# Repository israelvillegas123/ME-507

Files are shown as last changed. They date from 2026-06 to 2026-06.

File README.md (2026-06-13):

# Desk Buddy Robot

Desk Buddy is a small autonomous desk companion robot built around an STM32F411 microcontroller. The robot uses VL53L0X Time of Flight sensors to avoid falling off a desk, DC motors with encoders for movement, servo-driven llama ears for expressive behavior, and an SSD1306 OLED display for facial animations.

## Documentation

Project documentation can be found at:
(https://israelvillegas123.github.io/ME-507/index.html)

## Repository Structure

- Core/ - Application source code
- Drivers/ - STM32 HAL drivers
- USB_DEVICE/ - USB CDC implementation
- docs/ - Doxygen documentation pages
- Doxyfile - Doxygen configuration

## Authors

- Israel Villegas
- Antony Chen

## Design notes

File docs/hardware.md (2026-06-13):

# Hardware {#hardware}

## Hardware Overview

The Desk Buddy is built around an STM32F411 microcontroller and a custom PCB that connects all of the sensors, motors, and user interface components. The robot uses sensors to detect the edge of a desk, while motors and servos allow it to move and interact with the user.

---

## Main Controller

### STM32F411CEU6

The STM32F411CEU6 is the main microcontroller used in the project. It acts as the brain of the robot and is responsible for reading sensor data, controlling the motors and servos, updating the display, and making decisions about how the robot should behave.

---

## Sensors

### Time of Flight Sensors

Three VL53L0X Time of Flight distance sensors are mounted on the front of the robot. These sensors measure the distance to nearby objects and help the robot from falling off the edge. The VL53L0X sensors communicate with the STM32 microcontroller using the I2C interface and provide accurate distance measurements in a compact package.

---

## Actuators

### DC Motors with Encoders

The robot moves using two DC gear motors. Each motor includes an encoder that measures wheel rotation. The encoder feedback allows the software to monitor wheel speed and improve motor control.

### Servo Motors

Two servo motors are used to move the robot's arms. These arms are used to give the robot personality and make it feel more interactive.

---

## User Interface

### OLED Display

A SSD1306 OLED display is mounted on the front of the robot and is used to show facial expressions and animations. The display communicates with the STM32 microcontroller over an I2C interface and serves as the primary visual interface for the robot.

---

## Bill of Materials

| Component | Qty | Purpose |
| --- | ----- | --- |
| STM32F411CEU6 | 1 | Main microcontroller |
| DC Gear Motor with Encoder | 2 | Drive the robot and provide speed feedback |
| DRV8833 Motor Driver | 1 | Control the DC motors |
| Servo Motor | 2 | Move the robot arms |
| VL53L0X ToF Sensor | 3 | Distance measurement and edge detection |
| SSD1306 I2C OLED Display | 1 | Display faces and status information |
| 7.4 V LiPo Battery | 1 | Power source |

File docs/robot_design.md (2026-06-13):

# Robot Design {#robot_design}

## Overview

The Desk Buddy was designed to look like a small llama while still providing enough space for the electronics, battery, sensors, and motors.

The goal was to create a robot that feels more like a desk friend than a traditional robot. The final design has a simple design with features that give the robot personality, including movable ears and animated facial expressions displayed on an OLED screen.

---

## CAD Model

The robot was modeled in CAD before 3D printing it and checking overall dimensions.

<div align="center">
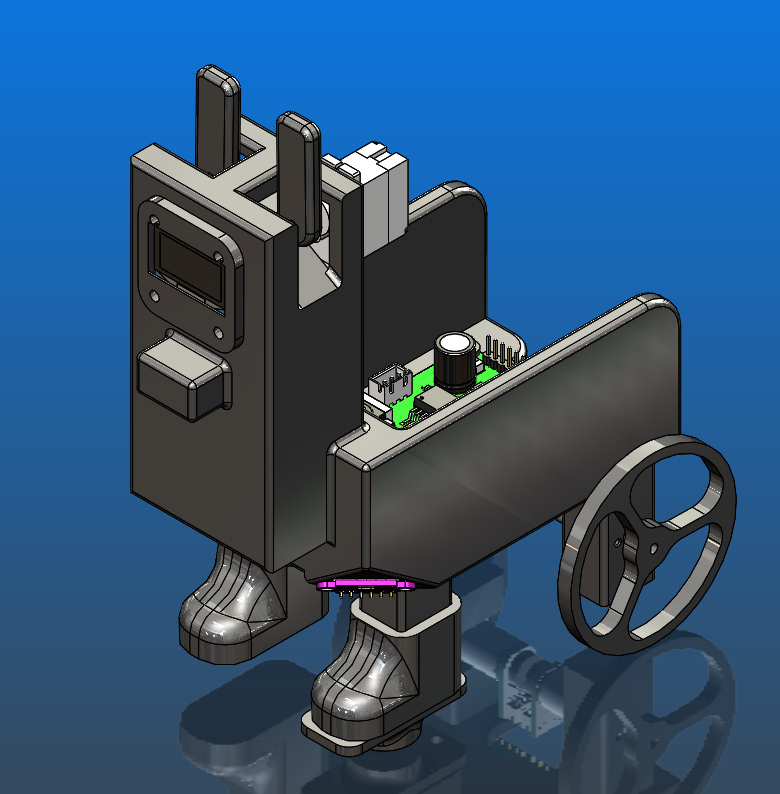
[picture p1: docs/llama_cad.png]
    
    <p><em>Figure 1: CAD model of the Desk Buddy robot.</em></p>
</div>

---

## Ear Mechanism

One of the main design goals was to give the robot personality.

Two servo-driven ears are mounted on top of the robot. These ears move independently and can be used to express different emotions or reactions.

Examples include:

* Sleeping
* Reacting to edges
* Indicating when being pet

<div align="center">
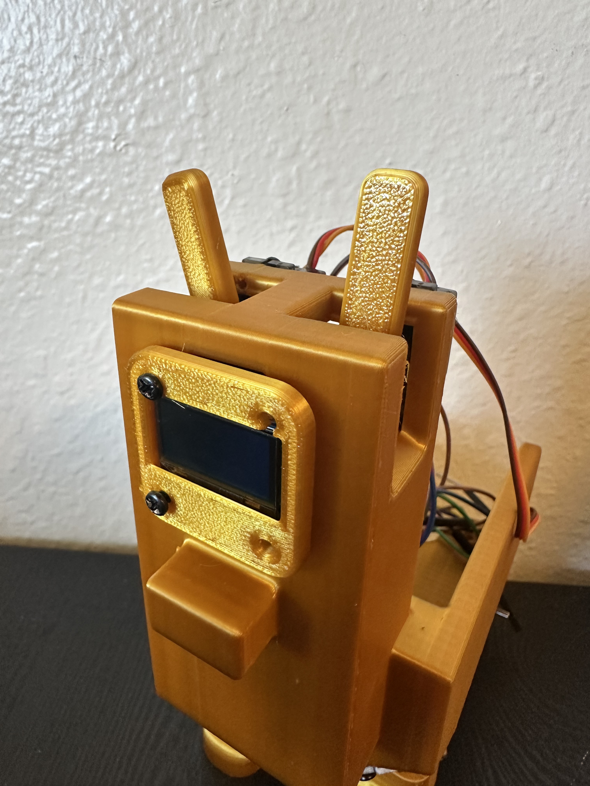
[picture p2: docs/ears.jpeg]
    
    <p><em>Figure 2: Ear mechanism.</em></p>
</div>

---

## Eyes and Display

An OLED display is mounted on the front of the robot.

The display is used to show:

* Eyes
* Differnet expressions
* Simple animations

This helps make the robot feel more interactive and engaging.

<div align="center">
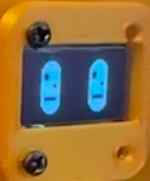
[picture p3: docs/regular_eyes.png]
    
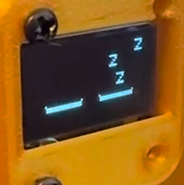
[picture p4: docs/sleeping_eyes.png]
    
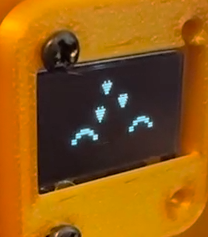
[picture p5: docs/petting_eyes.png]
    
    <p><em>Figure 3: Different eye settings.</em></p>
</div>

---

## Drive System

The robot is driven by two DC gear motors with an encoders. We have caster wheels to provide stability while allowing smooth movement. 
The motors speed is controlled by a PI controller so that the robot drive at one set speed.

---

## Sensor Placement

The sensors were positioned to allow the robot to safely move around a desk. This arrangement allows the robot to read the distance from mutliple direction which prevents it falling off the edge.

<div align="center">
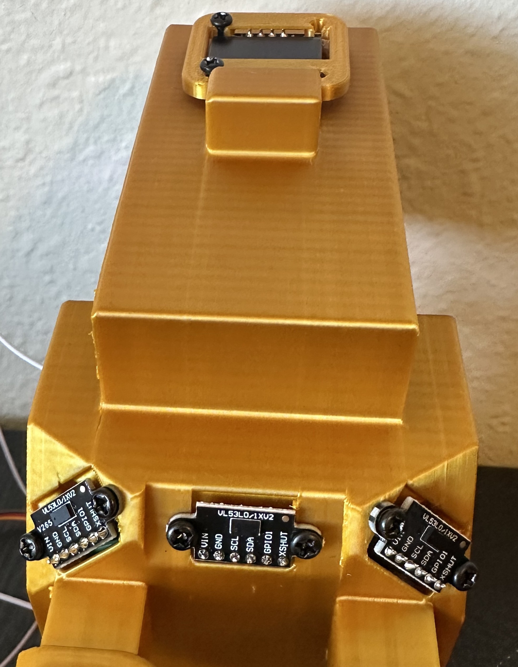
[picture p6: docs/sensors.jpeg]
    
    <p><em>Figure 4: Sensor positions.</em></p>
</div>

---

## Manufacturing

The entire thing was 3D printed in PLA filament. This allowed for quick iterations and low cost construction.

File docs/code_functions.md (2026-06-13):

# Code Functions {#code_functions}

This page lists the main documented firmware functions used in the Desk Buddy project.

## Motor Control

- \link Motor_Init Motor_Init() \endlink
- \link Motor_Enable Motor_Enable() \endlink
- \link Motor_Disable Motor_Disable() \endlink
- \link Motor_Set_Duty Motor_Set_Duty() \endlink
- \link Motor_Stop Motor_Stop() \endlink

## Llama Ear Servo Control

- \link Servo_Init Servo_Init() \endlink
- \link Servo_SetAngle Servo_SetAngle() \endlink
- \link Servo_WiggleEars Servo_WiggleEars() \endlink
- \link Servo_Ears_Down Servo_Ears_Down() \endlink
- \link Servo_Ears_Up Servo_Ears_Up() \endlink

## OLED Display

- \link screen_Init screen_Init() \endlink
- \link screen_Clear screen_Clear() \endlink
- \link screen_UpdateScreen screen_UpdateScreen() \endlink
- \link screen_DrawPixel screen_DrawPixel() \endlink
- \link screen_AnimateEyes screen_AnimateEyes() \endlink
- \link screen_AnimateSleepEyes screen_AnimateSleepEyes() \endlink
- \link screen_AnimatePetEyes screen_AnimatePetEyes() \endlink
- \link screen_AnimateScaredFace screen_AnimateScaredFace() \endlink

## Distance Sensors

- \link task_distance_initialize task_distance_initialize() \endlink
- \link TOF_I2C_Scan_With_Both_On TOF_I2C_Scan_With_Both_On() \endlink
- \link TOF_InitTwo TOF_InitTwo() \endlink
- \link TOF_ReadTwo TOF_ReadTwo() \endlink
## Main Control Functions

- \link Switch_IsOn Switch_IsOn() \endlink
- \link mode_sleep mode_sleep() \endlink
- \link mode_pet mode_pet() \endlink
- \link mode_wonder mode_wonder() \endlink
- \link mode_falling mode_falling() \endlink
- \link Motor_ClosedLoop_Update Motor_ClosedLoop_Update() \endlink
- \link Motor_ClosedLoop_Reset Motor_ClosedLoop_Reset() \endlink

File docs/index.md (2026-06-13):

# Desk Buddy Robot

## Project Overview

The Desk Buddy is a small robot that can move around a desk on its own while interacting with the user. The goal of the project is to create a robot that can stay away from the edge of a desk, and show simple emotions through ear movements and facial expressions on a display.

The robot is controlled by an STM32F411CEU6 microcontroller mounted on a custom PCB. It uses two DC motors with encoders for movement, two servo motors for ear motion, and Time of Flight sensors for edge detection. An OLED display is used to show faces and animations, while buttons allow the user to interact with the robot.

This project combines embedded programming, PCB design, sensor integration, motor control, and mechanical design into a single system.

<div align="center">
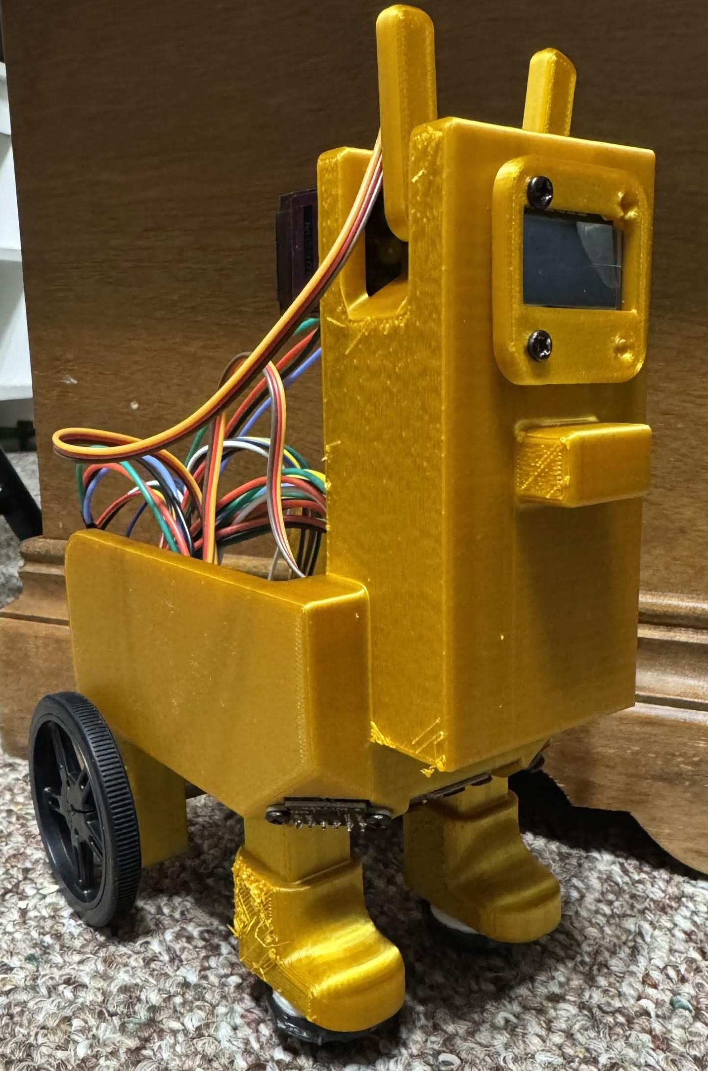
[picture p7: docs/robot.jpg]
    
    <p><em>Figure 1: Final robot assembly.</em></p>
</div>

\htmlonly
<div align="center">
    <video width="400" controls>
        <source src="demo.mp4" type="video/mp4">
        Your browser does not support the video tag.
    </video>
    <p><em>Figure 2: Desk Buddy demonstration.</em></p>
</div>
\endhtmlonly

---

## Project Features

* Drives around a desk without falling off
* Uses encoder feedback for motor control
* Custom PCB based on an STM32F411CEU6
* OLED display for facial expressions
* Servo driven ears for movement and interaction

## Major Hardware Components

| Component | Purpose |
| --- | --- |
| STM32F411CEU6 | Main microcontroller |
| DC Motors with Encoders | Movement and speed feedback |
| Servo Motors | Ear movement |
| ToF Sensors | Edge detection |
| OLED Display | Facial expressions and feedback |
| Custom PCB | Connects and controls all electronics |

---

## Source Code

The complete source code for the Desk Buddy project is available on GitHub.
GitHub Repository:
https://github.com/israelvillegas123/ME-507

---

## Documentation

### Hardware

@subpage hardware

### Custom PCB

@subpage pcb

### Robot Design

@subpage robot_design

### Software 

@subpage software

### Modeling and Control

@subpage modeling

### Code Functions

@subpage code_functions

---

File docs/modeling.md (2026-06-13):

# Modeling and Control {#modeling}

## Overview

This page describes the sensing, control logic, and motion control techniques used by the Desk Buddy.

The robot uses VL53L0X Time of Flightsensors to detect nearby objects and desk edges. The STM32 microcontroller processes this information and determines the robot's behavior.

The main goals of the control system are:

* Detect the edge of a desk before falling
* React to user interaction
* Control the wheel motors for movement
* Animate the display and llama ears to express emotion

---

## Distance Measurement

The Desk Buddy uses three VL53L0X Time-of-Flight sensors.

These sensors measure the distance between the robot and nearby objects by timing how long it takes for a laser pulse to reflect back to the sensor.

Distance measurements are reported in millimeters and are continuously updated.

---

## Pet Detection

One of the ToF sensors is used to detect when an hand is close to the robot.

When the measured distance falls below a threshold, the robot enters Pet mode.

In pet mode, the robot displays happy eyes with animated hearts and wiggles its ears.

---

## Edge Detection

Preventing the robot from falling off a desk is the highest priority control task.

When the robot is safely on the desk, the sensors measure a small distance to the desk surface. As the robot approaches the edge, the measured distance increases because the sensor no longer sees the desk under it.

The software uses a simple threshold to detect this condition.

When an edge is detected, the robot enters Falling mode and turns away from the edge.

---

## Encoder Feedback

Each drive motor contains a quadrature encoder that measures wheel rotation.

The encoder generates pulses as the wheel rotates. These pulses are counted by the STM32 using external interrupts.

Encoder feedback gives information about wheel movement and is used for closed loop speed control.

Each encoder has a 12 count per revolution.

The gearmotor has a gear ratio of 150.58:1, meaning the encoder measures motor shaft rotation before the gearbox.

The effective encoder resolution at the wheel is:

Encoder Counts per Wheel Revolution

= 12 × 150.58

= 1807 counts/revolution

This high encoder resolution allows the STM32 to accurately estimate wheel speed and wheel position.

---

## Closed-Loop Motor Control

To improve driving, encoder data can be compared to a desired wheel speed.

The difference between the desired speed and measured speed is the error.

A proportional integral controller can then change the motor PWM duty cycle to reduce this error.

This allows the robot to keep a more consistent speed and compensate for differences between the left and right motors.

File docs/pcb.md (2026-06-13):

# Custom PCB {#pcb}

## Overview

The Desk Buddy uses a custom PCB to connect and control all of the main electronics on the robot.

The PCB holds the STM32 microcontroller, power regulation parts, motor driver, connectors, sensors, and supporting components. This keeps the wiring cleaner and makes the robot easier to assemble compared to using a bunch of separate breakout boards.

<div align="center">
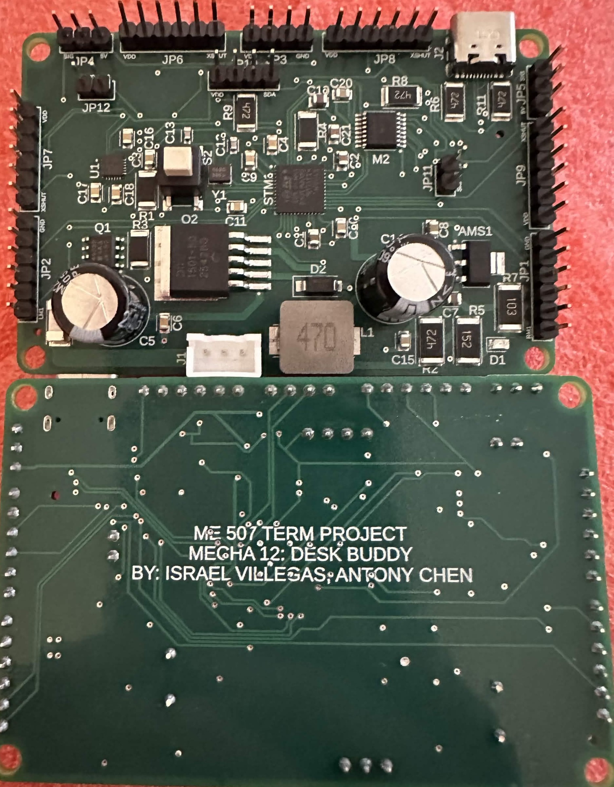
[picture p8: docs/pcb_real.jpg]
    
    <p><em>Figure 1: Final PCB assembly.</em></p>
</div>

<div align="center">
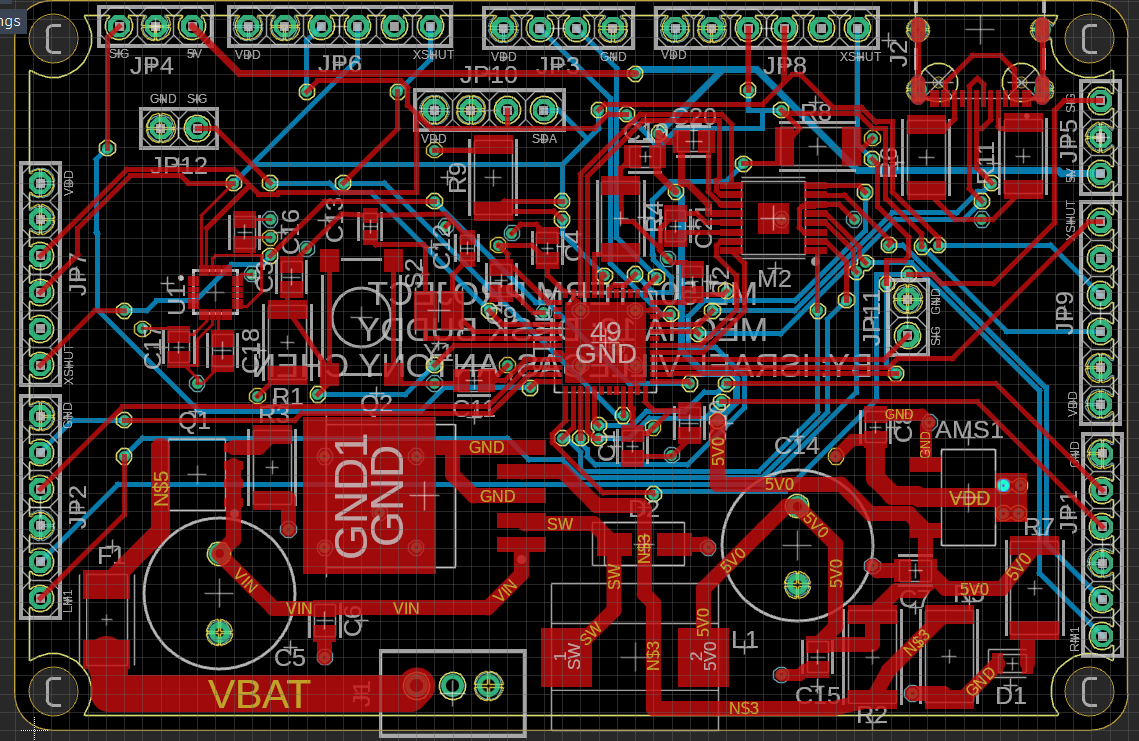
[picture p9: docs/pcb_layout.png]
    
    <p><em>Figure 2: PCB layout and traces.</em></p>
</div>

---

## Main PCB Features

The PCB includes:

- STM32F411 microcontroller
- 5 V buck converter
- 3.3 V linear regulator
- DRV8833 motor driver
- USB-C connector
- ICM-20948 IMU
- Crystal oscillator
- Connectors for motors, servos, ToF sensors, OLED display, and battery
- Fuse and protection components

---

## Power System

The robot is powered by a 7.4 V battery.

The PCB steps this voltage down to power the different parts of the robot:

| Voltage | Used For |
|---|---|
| 7.4 V Battery | Main power input |
| 5 V | Servos and DC motors |
| 3.3 V | STM32, sensors, and logic signals |

A fuse is included to help protect the board if something goes wrong.

---

## Motor Control

The PCB uses a DRV8833 motor driver to control the two DC motors.

The STM32 sends control signals to the motor driver, and the motor driver provides the power needed to drive the motors.

---

## Connectors

Pin headers are used to connect external parts to the PCB, including:

- DC motors
- Servo motors
- ToF sensors
- OLED screen
- Battery
- Programming/debug connections
- User interface parts

These connectors allow the the external parts send and recieve data from the board.

---

## PCB Bill of Materials

| Item | Quantity | Designator | JLCPCB Number | Source | Package |
|---|---|---|---|---|---|
| 3.3 V Linear Regulator | 1 | AMS1 | C6186 | JLCPCB | SOT-223 |
| 4.7 uF Capacitor | 2 | C1, C2 | C1779 | JLCPCB | 0805 |
| 100 nF Capacitor | 10 | C3, C4, C6, C9, C10, C11, C15, C16, C17, C18 | C1711 | JLCPCB | 0805 |
| 470 uF Capacitor | 2 | C5, C14 | C338188 | JLCPCB | Plugin, D10xL12.5mm |
| 10 uF Capacitor | 2 | C7, C19 | C15850 | JLCPCB | 0805 |
| 22 uF Capacitor | 1 | C8 | C29277 | JLCPCB | 0805 |
| 6 pF Capacitor | 2 | C12, C13 | C170142 | JLCPCB | 0603 |
| 0.01 uF Capacitor | 1 | C20 | C1710 | JLCPCB | 0805 |
| 2.2 uF Capacitor | 1 | C21 | C377773 | JLCPCB | 0805 |
| LED | 1 | D1 | C2292 | JLCPCB | 0805 |
| Diode | 1 | D2 | C8678 | JLCPCB | SMA / DO-214AC |
| 7 A Fuse | 1 | F1 | C3158084 | JLCPCB | SMD, 6.1x2.5mm |
| 3 Pin XH Header | 1 | J1 | C144394 | JLCPCB | Plugin, P=2.5mm |
| USB-C Connector | 1 | J2 | C3025063 | JLCPCB | SMD |
| 1x6 Pin Header | 6 | JP1, JP2, JP6, JP7, JP8, JP9 | C5444523 | JLCPCB | Plugin, P=2.54mm |
| 1x2 Pin Header | 2 | JP11, JP12 | C2915055 | JLCPCB | Plugin, P=2.54mm |
| 1x4 Pin Header | 2 | JP3, JP10 | C5184785 | JLCPCB | Plugin, P=2.54mm |
| 1x3 Pin Header | 2 | JP4, JP5 | C2915006 | JLCPCB | Plugin, P=2.54mm |
| 46 uH Inductor | 1 | L1 | C6364681 | JLCPCB | SMD, 11.6x10.1mm |
| DRV8833 Motor Driver | 1 | M2 | C50506 | JLCPCB | TSSOP-16-EP |
| P-Channel MOSFET | 1 | Q1 | C727481 | JLCPCB | 8-SO |
| 5 V Buck Converter | 1 | Q2 | C9980 | JLCPCB | TO-263-5 |
| 10k 1 W Resistor | 3 | R1, R3, R4 | C2081198 | JLCPCB | 2010 |
| 4.7k 2 W Resistor | 1 | R2 | C33178 | JLCPCB | 2512 |
| 1.5k 2 W Resistor | 1 | R5 | C26071 | JLCPCB | 2512 |
| 4.7k 1 W Resistor | 4 | R6, R8, R9, R11 | C2770395 | JLCPCB | 2010 |
| 10k 2 W Resistor | 1 | R7 | C25718 | JLCPCB | 2512 |
| Switch | 1 | S2 | C22438501 | JLCPCB | SMD-4P, 5.9x5.9mm |
| STM32F411CEU6 | 1 | STM1 | C60420 | JLCPCB | UFQFPN-48, 7x7mm |
| ICM-20948 IMU | 1 | U1 | C726001 | JLCPCB | QFN-24, 3x3mm |
| Crystal | 1 | Y1 | C189764 | JLCPCB | SMD3225-2P |
| DC Motors | 2 | N/A | 5210 | Pololu | N/A |
| Servo Motors | 2 | N/A | N/A | Amazon | N/A |
| 7.4 V Battery | 1 | N/A | N/A | N/A | N/A |
| ToF Sensors | 4 | N/A | N/A | Amazon | N/A |
| OLED Screen | 1 | N/A | N/A | Amazon | N/A |

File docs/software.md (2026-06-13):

# Software{#software}

## Overview

The Desk Buddy software controls how the robot moves, reacts to sensor input, displays emotions, and responds to user interaction.

The software runs on an STM32F411 microcontroller and is written in C using STM32CubeIDE. The robot uses VL53L0X Time of Flight sensors for edge detection, PWM controlled DC motors for movement, servo motors for ear animation, and an SSD1306 OLED display for facial expressions.

---

## Main Loop

The robot operates using a continuously repeating main loop.

Each iteration of the loop checks the user button, reads sensor data, updates the robot's behavior, controls the motors, moves the ears, and updates the display.

Basic loop:

```text
while robot is running:
    check button
    read ToF sensors
    determine robot mode
    control motors
    move ears
    update display
```

The robot checks edge detection before normal driving behavior to make sure that it does not fall off.

---

## Software Structure

The software is organized into separate modules to improve readability and simplify debugging.

| Software Module | Purpose |
|---|---|
| main.c | Main robot behavior and decision making |
| task_distance.c | VL53L0X sensor initialization and distance measurements |
| motor.c | DC motor control using PWM |
| servo.c | Llama ear movement control |
| screen.c | OLED graphics and facial animations |

---

## Robot Modes

The robot operates using several behavior modes.

| Mode | Description |
| --- | --- |
| Sleep | Stops the motors, lowers the ears, and displays sleeping eyes |
| Pet | Displays happy eyes and wiggles the ears when an object is detected nearby |
| Wonder  | Normal operating mode with animated eyes and forward movement |
| Falling | Displays a scared face and turns away from the desk edge |

---

## Behavior Logic

The robot uses simple condition based decision making.

First, the user button is checked. If the button is pressed, the robot enters Sleep mode.

The robot then reads the VL53L0X sensors.

If an object is detected very close to the robot, it enters Pet mode. If either sensor detects a large distance which is the edge of a desk, the robot enters Falling mode and turns away from the edge.

Otherwise, the robot enters Wonder mode and continues moving forward.

---

## Motor Control

The robot uses two DC gear motors driven through DRV8833 motor drivers.

Motor speed and direction are controlled using PWM signals generated by the STM32 timers.

Each DC gear motor includes an encoder that measures wheel rotation. The encoder signals are connected to external interrupt pins on the STM32. Each time an encoder pulse is detected, the software updates the left or right encoder count.

The robot uses these encoder counts to estimate wheel speed. A simple closed-loop controller compares the measured wheel speed to a target speed and adjusts the PWM duty cycle sent to each motor. This helps the robot drive straighter because the software can compensate if one wheel is moving faster than the other.

In normal driving mode, the robot continuously updates the motor PWM values using encoder feedback. During edge avoidance, the robot uses a fixed turning command so it can quickly move away from the desk edge.

---

## Sensor Logic

The robot uses VL53L0X Time of Flight sensors to detect nearby objects and desk edges.

The sensors continuously measure distance and provide feedback to the main control loop.

This allows the robot to react to nearby objects while avoiding falls.

---

## OLED Display

An SSD1306 OLED display provides animated facial expressions that help give the robot personality.

The display supports several animations:

* Normal blinking eyes
* Sleeping eyes with animated "Z" symbols
* Happy eyes with floating hearts
* Scared face for edge detection

The display is updated through the I2C interface.

---

## Ear Servo Control

The Desk Buddy uses two servo motors to move its llama ears.

The ears are used to communicate the robot's emotional state and make interactions feel more natural.

| Robot Mode | Ear Behavior |
| --- | --- |
| Sleep | Ears lowered |
| Pet | Ears wiggle continuously |
| Wonder | Ears raised |
| Falling | Ears raised in alert position |

The servos are controlled using PWM signals generated by the STM32 timers.

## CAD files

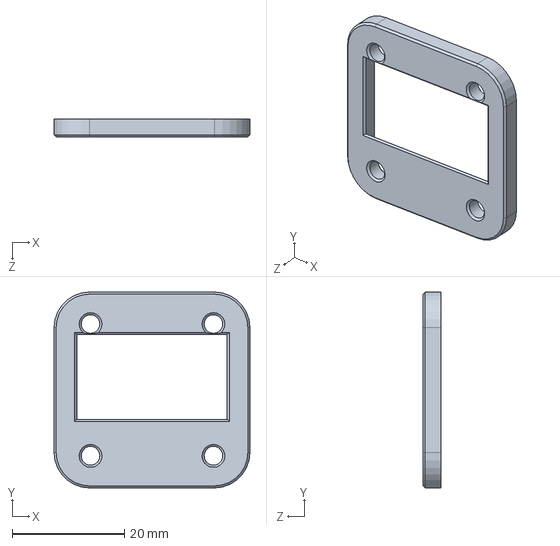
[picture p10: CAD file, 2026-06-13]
CAD/mask.SLDPRT
34.9 x 34.9 x 3.17 mm

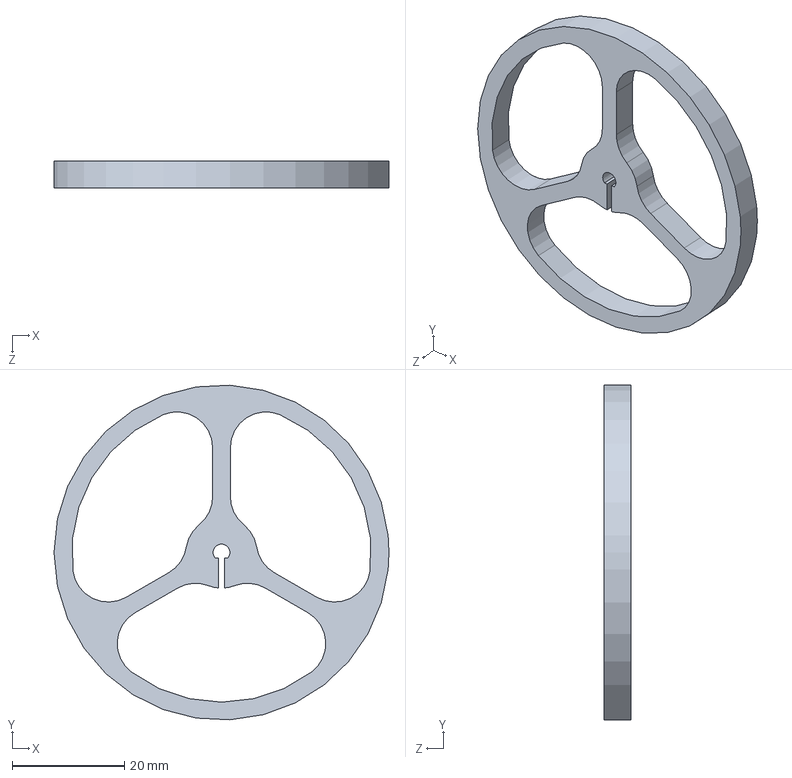
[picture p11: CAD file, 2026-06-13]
CAD/Wheel.SLDPRT
59.7 x 59.6 x 4.76 mm

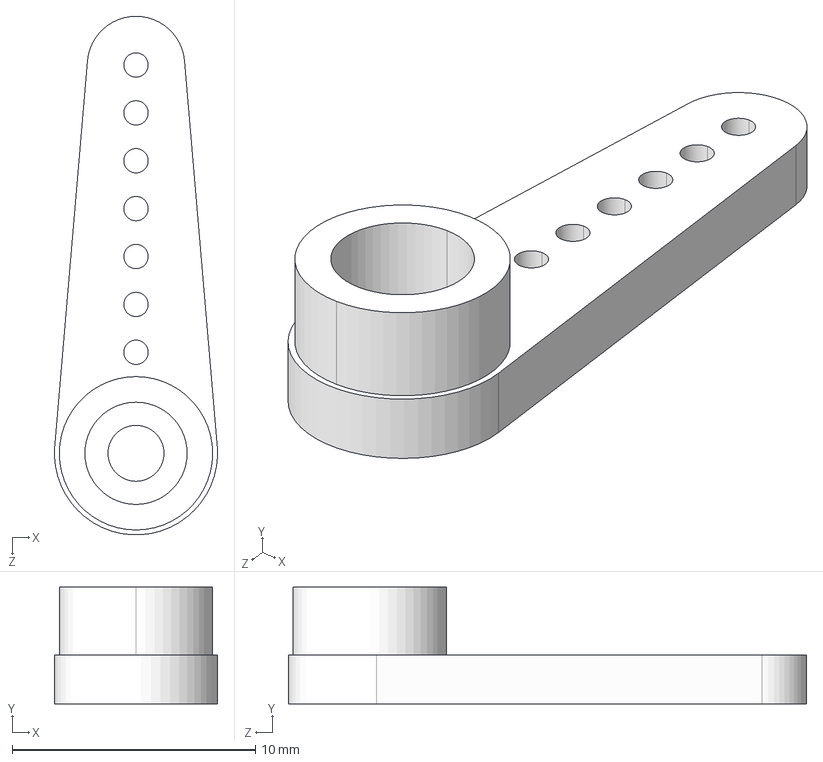
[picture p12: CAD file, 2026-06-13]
CAD/MG90S horn.STEP
6.70 x 4.80 x 21.3 mm

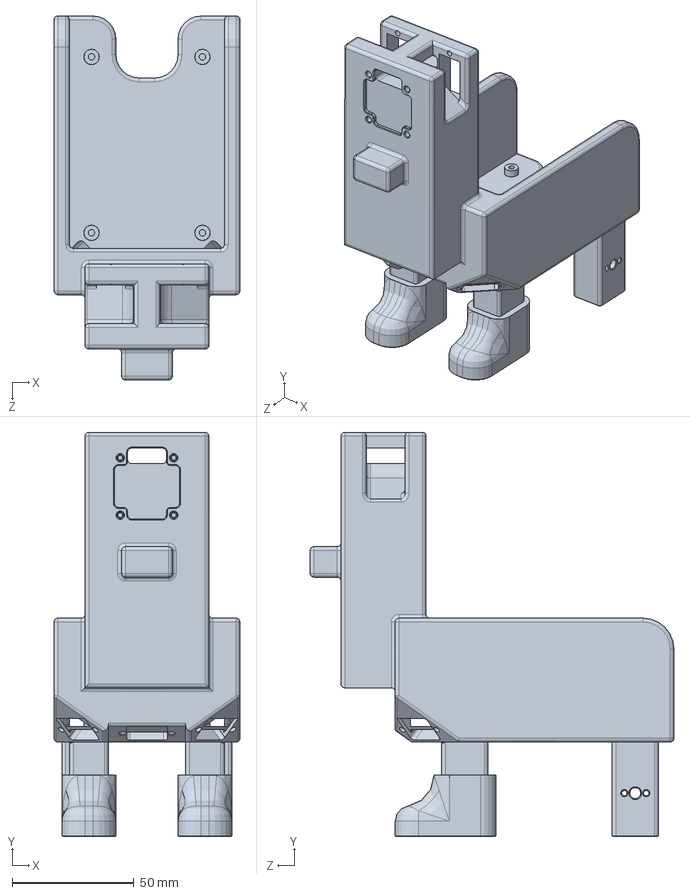
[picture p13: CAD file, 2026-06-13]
CAD/ecample.SLDPRT
76.2 x 165.8 x 149.2 mm

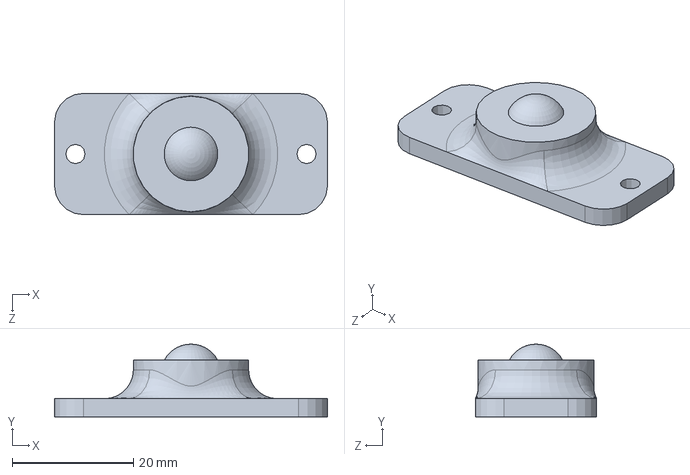
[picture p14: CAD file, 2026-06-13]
CAD/wheel ball.SLDPRT
45.0 x 12.0 x 20.0 mm

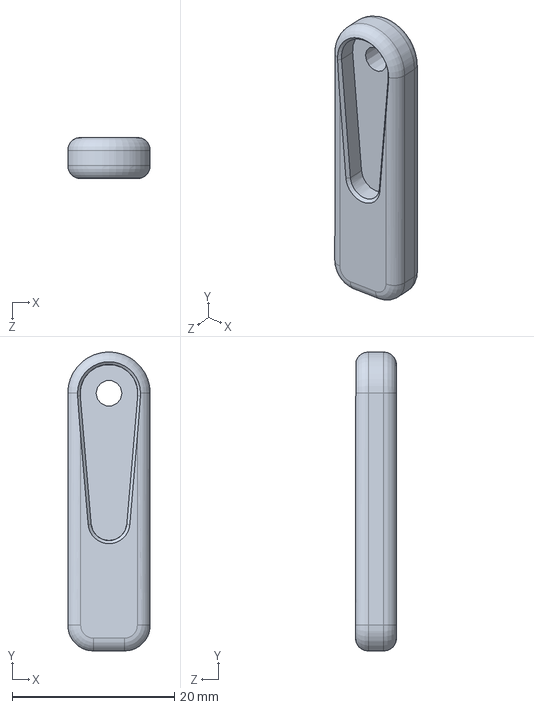
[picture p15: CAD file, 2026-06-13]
CAD/ear.SLDPRT
10.2 x 36.8 x 5.08 mm

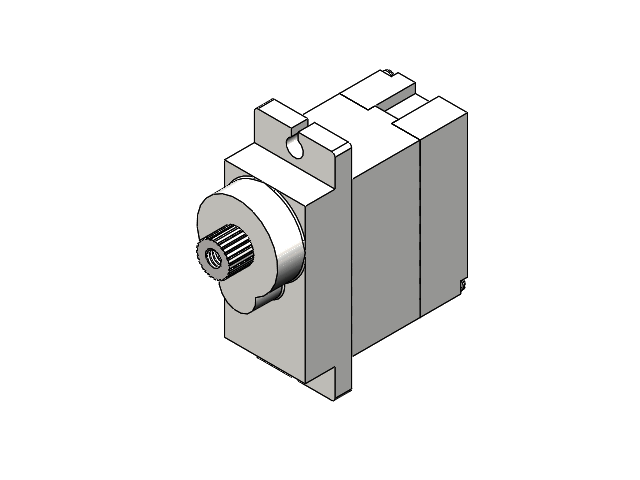
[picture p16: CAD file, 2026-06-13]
CAD/Assembly Micro Servo MG90S.SLDASM
Micro Motor.step
Middel Part.step
Buttom Part.step
Shaft B.step
Gear C.step
Gear B.step
Gear A.step
Main Shaft with Gear.step
Upper Part.step
Main Screw.step x 2

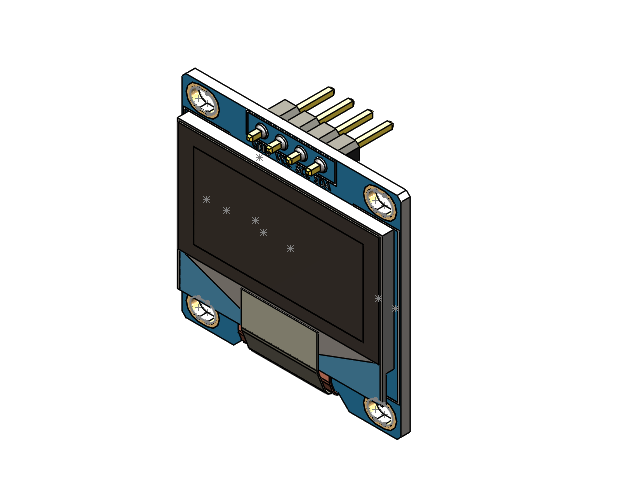
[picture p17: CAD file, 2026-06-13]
CAD/Pantalla OLED 0.96'' 128x64.SLDASM
STEP OLED Display 128x64.stp
SOT-23_TOR.stp
RES_CR16_MTK_1.stp x 4
RES_CR16_MTK.stp
0603.stp x 8
SOD323F_DIO.stp

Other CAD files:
CAD/MG90S horn.SLDPRT

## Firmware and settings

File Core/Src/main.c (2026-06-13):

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

#include "main.h"
#include "usb_device.h"

/* USER CODE BEGIN Includes */
#include "motor.h"
#include "servo.h"
#include "usbd_cdc_if.h"
#include "task_distance.h"
#include "usb_print.h"
#include "screen.h"
#include "servo.h"


#include <string.h>
#include <stdio.h>
#include <stdarg.h>
/* USER CODE END Includes */

/* USER CODE BEGIN PD */

#define ENABLE_MOTOR_SERVO_INIT 0

/* USER CODE END PD */

I2C_HandleTypeDef hi2c1;

TIM_HandleTypeDef htim1;
TIM_HandleTypeDef htim2;
TIM_HandleTypeDef htim4;

/* USER CODE BEGIN PV */

static motor_t left_motor =
{
    .timer = &htim1,
    .channel1 = TIM_CHANNEL_1,
    .channel2 = TIM_CHANNEL_2,
    .pwm_max = 4199
};

static motor_t right_motor =
{
    .timer = &htim4,
    .channel1 = TIM_CHANNEL_3,
    .channel2 = TIM_CHANNEL_4,
    .pwm_max = 4199
};

static Servo_t left_servo =
{
    .htim = &htim2,
    .channel = TIM_CHANNEL_3,
    .angle = 90
};

static Servo_t right_servo =
{
    .htim = &htim2,
    .channel = TIM_CHANNEL_4,
    .angle = 90
};

volatile int32_t left_encoder_count = 0;
volatile int32_t right_encoder_count = 0;

/* USER CODE END PV */

void SystemClock_Config(void);
static void MX_GPIO_Init(void);
static void MX_I2C1_Init(void);
static void MX_TIM1_Init(void);
static void MX_TIM2_Init(void);
static void MX_TIM4_Init(void);
/* USER CODE BEGIN PFP */
static void Debug_XSHUT_GPIO_After_USB_Start(void);
/* USER CODE END PFP */

/* USER CODE BEGIN 0 */

static void Debug_XSHUT_GPIO_After_USB_Start(void)
{
    HAL_GPIO_WritePin(TOF1_XShut_GPIO_Port, TOF1_XShut_Pin, GPIO_PIN_RESET);
    HAL_GPIO_WritePin(TOF2_XShut_GPIO_Port, TOF2_XShut_Pin, GPIO_PIN_RESET);
    HAL_Delay(100);

    USB_Printf("XSHUT low readback: TOF1=%d TOF2=%d\r\n",
               HAL_GPIO_ReadPin(TOF1_XShut_GPIO_Port, TOF1_XShut_Pin),
               HAL_GPIO_ReadPin(TOF2_XShut_GPIO_Port, TOF2_XShut_Pin));

    HAL_GPIO_WritePin(TOF1_XShut_GPIO_Port, TOF1_XShut_Pin, GPIO_PIN_SET);
    HAL_GPIO_WritePin(TOF2_XShut_GPIO_Port, TOF2_XShut_Pin, GPIO_PIN_SET);
    HAL_Delay(100);

    USB_Printf("XSHUT high readback: TOF1=%d TOF2=%d\r\n",
               HAL_GPIO_ReadPin(TOF1_XShut_GPIO_Port, TOF1_XShut_Pin),
               HAL_GPIO_ReadPin(TOF2_XShut_GPIO_Port, TOF2_XShut_Pin));

    HAL_GPIO_WritePin(TOF1_XShut_GPIO_Port, TOF1_XShut_Pin, GPIO_PIN_RESET);
    HAL_GPIO_WritePin(TOF2_XShut_GPIO_Port, TOF2_XShut_Pin, GPIO_PIN_RESET);
    HAL_Delay(150);
}


/**
 * @brief Runs sleep mode behavior.
 *
 * Stops normal interaction by showing sleeping eyes and lowering the llama ears.
 */
static void mode_sleep(void)
{
	screen_AnimateSleepEyes();
	Servo_Ears_Down(&left_servo, &right_servo);

}

/**
 * @brief Runs pet mode behavior.
 *
 * Displays happy eyes and wiggles the llama ears.
 */
static void mode_pet(void)
{
	screen_AnimatePetEyes();
	Servo_WiggleEars(&left_servo, &right_servo);


}

/**
 * @brief Runs normal wonder mode behavior.
 *
 * Displays animated eyes and raises the llama ears.
 */
static void mode_wonder(void)
{
	screen_AnimateEyes();
	Servo_Ears_Up(&left_servo, &right_servo);

}

/**
 * @brief Runs falling or edge-detection behavior.
 *
 * Displays a scared face and raises the ears in an alert position.
 */
static void mode_falling(void)
{
	screen_AnimateScaredFace();
	Servo_Ears_Up(&left_servo, &right_servo);

}
/**
 * @brief Reads the active-low user switch with debounce.
 *
 * @return 1 if the switch is pressed, 0 otherwise.
 */
static uint8_t Switch_IsOn(void)

    if (HAL_GPIO_ReadPin(Button1_GPIO_Port, Button1_Pin) == GPIO_PIN_RESET)
    {
        HAL_Delay(20);  

        if (HAL_GPIO_ReadPin(Button1_GPIO_Port, Button1_Pin) == GPIO_PIN_RESET)
        {
            return 1;
        }
    }

    return 0;
}

/* USER CODE END 0 */

#define CONTROL_DT_MS 20
#define LEFT_TARGET_CPS  250.0f
#define RIGHT_TARGET_CPS 250.0f
#define KP 1.2f
#define KI 0.08f

static float left_cmd = 50.0f;
static float right_cmd = 50.0f;
static float left_integral = 0.0f;
static float right_integral = 0.0f;

/**
 * @brief Updates closed-loop motor speed control.
 *
 * Estimates wheel speed using encoder count changes and adjusts motor PWM
 * using a PI controller.
 *
 * @param left_target_cps Desired left wheel speed in encoder counts per second.
 * @param right_target_cps Desired right wheel speed in encoder counts per second.
 */
static void Motor_ClosedLoop_Update(float left_target_cps, float right_target_cps)
    static uint32_t last_time = 0;
    static int32_t last_left_count = 0;
    static int32_t last_right_count = 0;

    uint32_t now = HAL_GetTick();

    if (last_time == 0)
    {
        last_time = now;
        last_left_count = left_encoder_count;
        last_right_count = right_encoder_count;
        return;
    }

    if (now - last_time < CONTROL_DT_MS)
        return;

    int32_t left_now = left_encoder_count;
    int32_t right_now = right_encoder_count;

    int32_t left_delta = left_now - last_left_count;
    int32_t right_delta = right_now - last_right_count;

    float dt = (now - last_time) / 1000.0f;

    float left_speed = left_delta / dt;
    float right_speed = right_delta / dt;

    float left_error = left_target_cps - left_speed;
    float right_error = right_target_cps - right_speed;

    left_integral += left_error * dt;
    right_integral += right_error * dt;

    left_cmd += KP * left_error + KI * left_integral;
    right_cmd += KP * right_error + KI * right_integral;

    if (left_cmd > 100.0f) left_cmd = 100.0f;
    if (left_cmd < -100.0f) left_cmd = -100.0f;
    if (right_cmd > 100.0f) right_cmd = 100.0f;
    if (right_cmd < -100.0f) right_cmd = -100.0f;

    Motor_Set_Duty(&left_motor, left_cmd);
    Motor_Set_Duty(&right_motor, right_cmd);

    last_left_count = left_now;
    last_right_count = right_now;
    last_time = now;
}

/**
 * @brief Resets the closed-loop motor controller.
 *
 * Clears integral terms and restores initial motor command values.
 */
static void Motor_ClosedLoop_Reset(void)
{
    left_integral = 0.0f;
    right_integral = 0.0f;
    left_cmd = 50.0f;
    right_cmd = 50.0f;
}

int main(void)
{
  HAL_Init();

  SystemClock_Config();

  MX_GPIO_Init();
  MX_I2C1_Init();
  MX_TIM1_Init();
  MX_TIM2_Init();
  MX_TIM4_Init();


  /* USER CODE BEGIN 2 */
	#if USB_DEBUG_ENABLED
	  MX_USB_DEVICE_Init();
	  HAL_Delay(1500);
	  USB_Print("\r\nUSB CDC started\r\n");
	#endif



  task_distance_initialize();



  Motor_Init(&left_motor);
  Motor_Init(&right_motor);
  Motor_Enable();

  Servo_Init(&left_servo);
  Servo_SetAngle(&left_servo, 180);
  Servo_Init(&right_servo);
  Servo_SetAngle(&right_servo, 0);



  screen_Init(&hi2c1);
  /* USER CODE END 2 */

  while (1)
  {
	    if (Switch_IsOn())
	    {
	    	mode_sleep();
	    	Motor_Set_Duty(&left_motor, 0.0f);
	    	Motor_Set_Duty(&right_motor, 0.0f);
	    	continue;
	    }
	    TOF_Measurement_t tof1_measure;
	    TOF_Measurement_t tof2_measure;

	    TOF_ReadTwo(&tof1_measure, &tof2_measure);
	    if (tof2_measure.distance_mm < 60)
	    {
	    	mode_pet();
	    	continue;
	    } else if(tof1_measure.distance_mm > 200 || tof2_measure.distance_mm > 200)
	    {
	    	mode_falling();
        Motor_ClosedLoop_Reset();
        Motor_Set_Duty(&left_motor, -100.0f);
        Motor_Set_Duty(&right_motor, 100.0f);
	    	continue;
	    }
	    mode_wonder();
      Motor_ClosedLoop_Update(LEFT_TARGET_CPS, RIGHT_TARGET_CPS);

	    HAL_Delay(10);
  }
}

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
/* USER CODE BEGIN 4 */
void HAL_GPIO_EXTI_Callback(uint16_t GPIO_Pin)
{
    if (GPIO_Pin == GPIO_PIN_0)
    {
        if (HAL_GPIO_ReadPin(GPIOA, GPIO_PIN_1) == GPIO_PIN_SET)
        {
            left_encoder_count++;
        }
        else
        {
            left_encoder_count--;
        }
    }
    else if (GPIO_Pin == GPIO_PIN_6)
    {
        if (HAL_GPIO_ReadPin(GPIOA, GPIO_PIN_7) == GPIO_PIN_SET)
        {
            right_encoder_count++;
        }
        else
        {
            right_encoder_count--;
        }
    }
}
/* USER CODE END 4 */

void Error_Handler(void)
{
  __disable_irq();
  while (1)
  {
  }
}

#ifdef USE_FULL_ASSERT
void assert_failed(uint8_t *file, uint32_t line)
{
  (void)file;
  (void)line;
}
#endif

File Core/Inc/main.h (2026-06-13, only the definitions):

#define Button2_Pin GPIO_PIN_15
#define Button2_GPIO_Port GPIOC
#define Motor_NFault_Pin GPIO_PIN_4
#define Motor_NFault_GPIO_Port GPIOA
#define Motor_NSleep_Pin GPIO_PIN_5
#define Motor_NSleep_GPIO_Port GPIOA
#define TOF1_XShut_Pin GPIO_PIN_12
#define TOF1_XShut_GPIO_Port GPIOB
#define TOF2_XShut_Pin GPIO_PIN_13
#define TOF2_XShut_GPIO_Port GPIOB
#define TOF3_XShut_Pin GPIO_PIN_14
#define TOF3_XShut_GPIO_Port GPIOB
#define Button1_Pin GPIO_PIN_15
#define Button1_GPIO_Port GPIOB
#define SWDIO_Pin GPIO_PIN_13
#define SWDIO_GPIO_Port GPIOA
#define SWCLK_Pin GPIO_PIN_14
#define SWCLK_GPIO_Port GPIOA

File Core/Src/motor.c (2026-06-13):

/**
 * @file motor.c
 * @brief DC motor control functions.
 */
#include "motor.h"

/**
 * @brief Initializes a DC motor PWM interface.
 *
 * Starts both PWM channels used by the motor driver and stops the motor.
 *
 * @param motor Pointer to the motor configuration structure.
 */
void Motor_Init(motor_t *motor)
{
    HAL_TIM_PWM_Start(motor->timer, motor->channel1);
    HAL_TIM_PWM_Start(motor->timer, motor->channel2);

    Motor_Stop(motor);
}

/**
 * @brief Enables the DRV8833 motor driver.
 *
 * Sets the motor driver's nSLEEP pin high so the motors can operate.
 */
void Motor_Enable(void)
{
    HAL_GPIO_WritePin(Motor_NSleep_GPIO_Port, Motor_NSleep_Pin, GPIO_PIN_SET);
    HAL_Delay(2);
}

/**
 * @brief Disables the DRV8833 motor driver.
 *
 * Sets the motor driver's nSLEEP pin low to place the driver into sleep mode.
 */
void Motor_Disable(void)
{
    HAL_GPIO_WritePin(Motor_NSleep_GPIO_Port, Motor_NSleep_Pin, GPIO_PIN_RESET);
}

/**
 * @brief Checks whether the motor driver fault pin is active.
 *
 * @return 1 if a fault is active, 0 otherwise.
 */
uint8_t Motor_FaultActive(void)
{
    return HAL_GPIO_ReadPin(Motor_NFault_GPIO_Port, Motor_NFault_Pin) == GPIO_PIN_RESET;
}

/**
 * @brief Sets motor speed and direction using PWM duty cycle.
 *
 * Positive values rotate the motor forward, negative values rotate it in reverse,
 * and zero stops the motor.
 *
 * @param motor Pointer to the motor configuration structure.
 * @param duty_percent Duty cycle from -100.0 to 100.0 percent.
 */
void Motor_Set_Duty(motor_t *motor, float duty_percent)
{
    if (duty_percent > 100.0f) duty_percent = 100.0f;
    if (duty_percent < -100.0f) duty_percent = -100.0f;

    float abs_duty = duty_percent;
    if (abs_duty < 0.0f)
    {
        abs_duty = -abs_duty;
    }

    uint32_t pwm = (uint32_t)(abs_duty * motor->pwm_max / 100.0f);

    if (duty_percent > 0.0f)
    {
        __HAL_TIM_SET_COMPARE(motor->timer, motor->channel1, pwm);
        __HAL_TIM_SET_COMPARE(motor->timer, motor->channel2, 0);
    }
    else if (duty_percent < 0.0f)
    {
        __HAL_TIM_SET_COMPARE(motor->timer, motor->channel1, 0);
        __HAL_TIM_SET_COMPARE(motor->timer, motor->channel2, pwm);
    }
    else
    {
        __HAL_TIM_SET_COMPARE(motor->timer, motor->channel1, 0);
        __HAL_TIM_SET_COMPARE(motor->timer, motor->channel2, 0);
    }
}

/**
 * @brief Stops the selected motor.
 *
 * @param motor Pointer to the motor configuration structure.
 */
void Motor_Stop(motor_t *motor)
{
    Motor_Set_Duty(motor, 0.0f);
}

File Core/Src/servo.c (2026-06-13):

/**
 * @file servo.c
 * @brief Llama ear control functions.
 */

#include "servo.h"

#define SERVO_MIN_US 1000
#define SERVO_MAX_US 2000

/**
 * @brief Initializes a servo PWM channel.
 *
 * @param servo Pointer to the servo configuration structure.
 */
void Servo_Init(Servo_t *servo)
{
    HAL_TIM_PWM_Start(servo->htim, servo->channel);
}

/**
 * @brief Sets the servo angle.
 *
 * Converts an angle from 0 to 180 degrees into a PWM pulse width.
 *
 * @param servo Pointer to the servo configuration structure.
 * @param angle Desired servo angle in degrees.
 */
void Servo_SetAngle(Servo_t *servo, uint8_t angle)
{
    if(angle > 180)
        angle = 180;

    servo->angle = angle;
    uint32_t pulse = SERVO_MIN_US + ((SERVO_MAX_US - SERVO_MIN_US) * angle) / 180;
    __HAL_TIM_SET_COMPARE(servo->htim, servo->channel, pulse);
}

/**
 * @brief Wiggles both llama ears.
 *
 * Creates a repeating ear motion by changing both servo angles over time.
 *
 * @param left Pointer to the left ear servo.
 * @param right Pointer to the right ear servo.
 */
void Servo_WiggleEars(Servo_t *left, Servo_t *right)
{
    static uint32_t lastMove = 0;
    static int8_t dir = 1;
    static int16_t pos = 0;

    uint32_t now = HAL_GetTick();

    if(now - lastMove < 40)
        return;

    lastMove = now;

    pos += dir * 10;

    if(pos >= 100)
        dir = -1;

    if(pos <= 0)
        dir = 1;

    Servo_SetAngle(left, pos);
    Servo_SetAngle(right, 110 - pos);
}

/**
 * @brief Moves both llama ears downward.
 *
 * @param left Pointer to the left ear servo.
 * @param right Pointer to the right ear servo.
 */
void Servo_Ears_Down(Servo_t *left, Servo_t *right)
{
    Servo_SetAngle(left, 0);
    Servo_SetAngle(right, 180);
}

/**
 * @brief Moves both llama ears upward.
 *
 * @param left Pointer to the left ear servo.
 * @param right Pointer to the right ear servo.
 */
void Servo_Ears_Up(Servo_t *left, Servo_t *right)
{
    Servo_SetAngle(left, 180);
    Servo_SetAngle(right, 0);
}

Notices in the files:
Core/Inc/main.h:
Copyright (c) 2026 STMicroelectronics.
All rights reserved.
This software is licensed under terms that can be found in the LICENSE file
